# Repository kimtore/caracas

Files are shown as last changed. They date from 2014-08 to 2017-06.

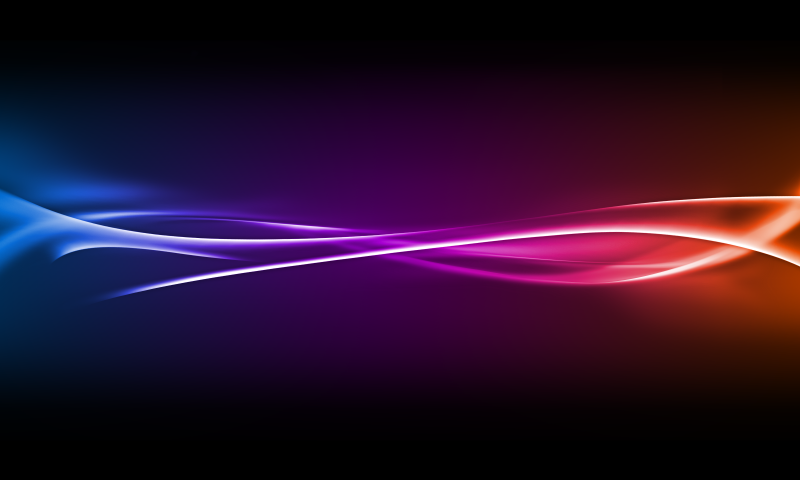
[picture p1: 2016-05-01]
etc/awesome/streamoflight.png

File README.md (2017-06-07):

# Caracas

Caracas is an open source DIY car stereo system for the Toyota Avensis 2007, running on Raspberry Pi with custom hardware modifications.

[See pictures](http://imgur.com/a/6FCoq) of Caracas in action!

## Features

* Front panel with volume button and a 800x480 resistive touch panel with backlight control.
* Control music and other functions using steering wheel control buttons.
* Ignition key detection: hardware controlled power-on, software-controlled power-off.
* Plays music using MPD, through a HIFImeDIY Sabre DAC ES9023 to a class D 400W RMS amplifier.
* ISO 10487 connection for power and speaker connections.
* Custom-designed Raspberry Pi HAT for interfacing with the car hardware.
* SSD disk stores huge amounts of music.
* 4G Internet connection using car antenna.
* GPS module using car antenna.
* Custom interface with music controls, using Qt.
* ~~World-wide road navigation using Marble and OpenStreetMap.~~

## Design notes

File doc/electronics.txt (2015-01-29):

http://www.electronics-tutorials.ws/transistor/tran_4.html

Voltage dividers:

    5V  -> 3.3V: r1=0.515*r2

    Try: r2 = 100k
         r1 = 47k

    12V -> 3.3V: r1=2.636*r2

    Try: r2 = 100k
         r1 = 290k

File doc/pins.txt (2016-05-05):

GPIO pin usage
--------------

8   TXD                 RS232   gps
10  RXD                 RS232   gps
16  Suicide out         OUTPUT  board, flip-flop reset
18  +12V ignition       INPUT   board, ignition on/off
20  GND                         header, rotary click
22  GPIO25              INPUT   header, rotary click
24  SPI CS              SPI     board
40  GPIO29              OUTPUT  display brightness 100Hz 3.3V PWM signal

7   GPCLK0              INPUT   gps, pulse per second
11  Amplifier power     OUTPUT  board, amplifier power switch
17  +3.3V to ADC
19  SPI MOSI            SPI
21  SPI MISO            SPI
23  SPI CLK             SPI
35  GPIO19              INPUT   header, rotary binary
37  GPIO26              INPUT   header, rotary binary
39  GND                         header, rotary binary

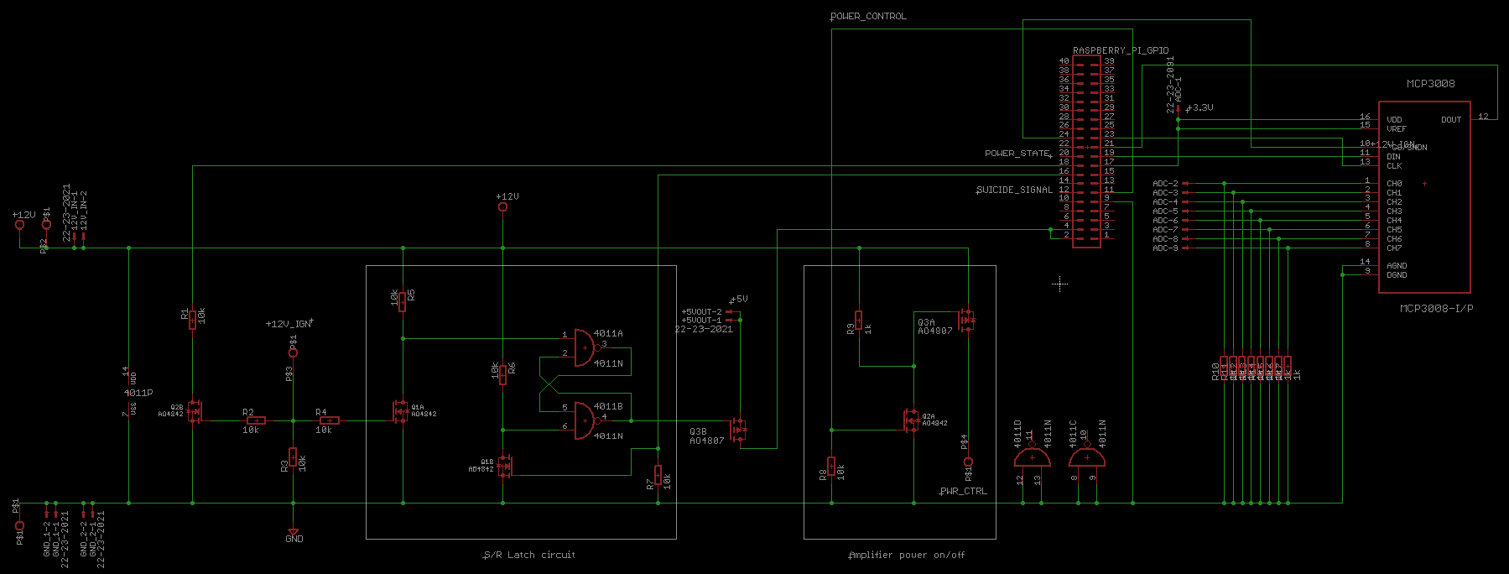
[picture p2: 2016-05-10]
doc/hat/schematic.png

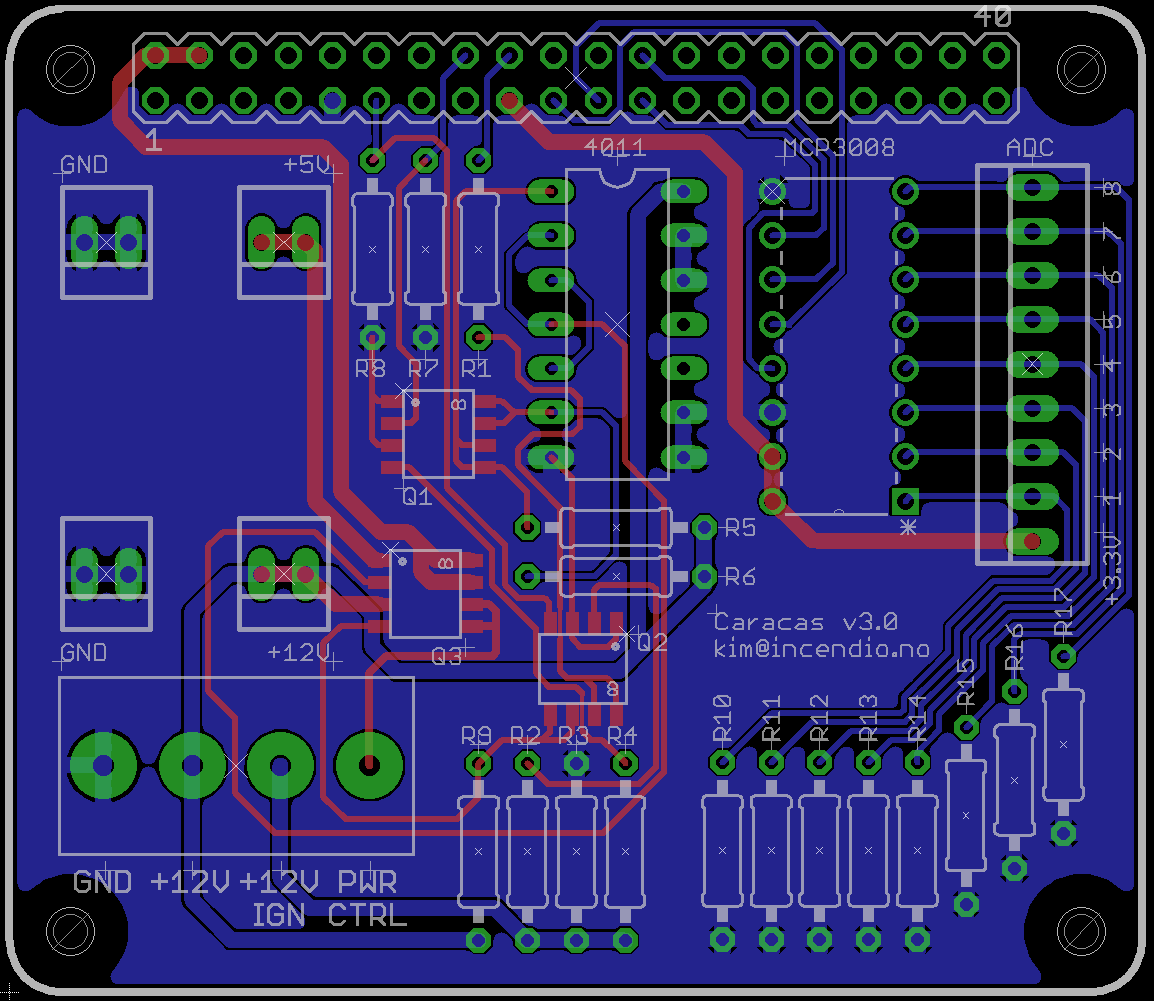
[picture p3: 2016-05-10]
doc/hat/layout.png

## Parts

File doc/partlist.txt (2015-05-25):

Partlist

Exported from untitled.sch at 5/25/15 12:14 PM

EAGLE Version 6.5.0 Copyright (c) 1988-2013 CadSoft

Assembly variant: 

Part              Value          Device       Package           Library   Sheet

+5VOUT            22-23-2021     22-23-2021   22-23-2021        con-molex 1
12V_IN            22-23-2021     22-23-2021   22-23-2021        con-molex 1
4011              4011N          4011N        DIL14             40xx      1
ADC               22-23-2091     22-23-2091   22-23-2091        con-molex 1
EXT               MKDS3          MKDS3        MKDS3             caracas   1
GND_1             22-23-2021     22-23-2021   22-23-2021        con-molex 1
GND_2             22-23-2021     22-23-2021   22-23-2021        con-molex 1
MCP1              MCP3008-I/P    MCP3008-I/P  DIP254P762X432-16 mpc3008   1
Q1                AO4842         AO4842       8-SOIC            caracas   1
Q2                AO4842         AO4842       8-SOIC            caracas   1
Q3                AO4807         AO4807       8-SOIC            caracas   1
R1                10k            R-EU_0207/10 0207/10           rcl       1
R2                10k            R-EU_0207/10 0207/10           rcl       1
R3                10k            R-EU_0207/10 0207/10           rcl       1
R4                10k            R-EU_0207/10 0207/10           rcl       1
R5                10k            R-EU_0207/10 0207/10           rcl       1
R6                10k            R-EU_0207/10 0207/10           rcl       1
R7                10k            R-EU_0207/10 0207/10           rcl       1
R8                10k            R-EU_0207/10 0207/10           rcl       1
R9                1k             R-EU_0207/10 0207/10           rcl       1
R10               1k             R-EU_0207/10 0207/10           rcl       1
R11               1k             R-EU_0207/10 0207/10           rcl       1
RASPBERRY_PI_GPIO                MA20-2       MA20-2            con-lstb  1

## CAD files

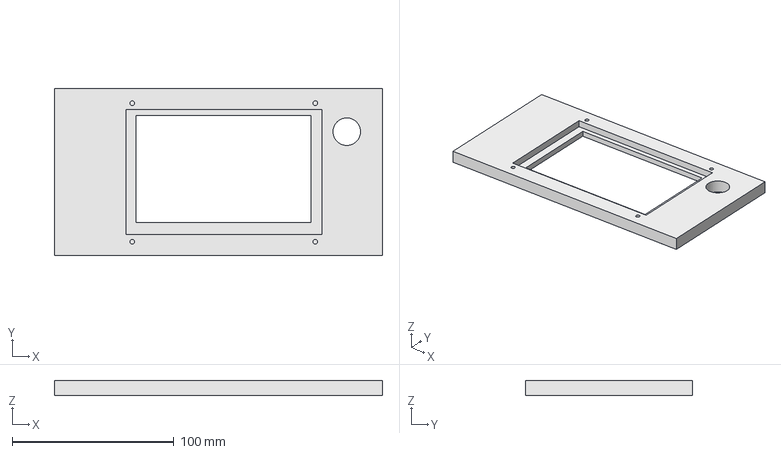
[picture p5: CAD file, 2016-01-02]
cad/panel.fcstd
202.5 x 102.9 x 9.00 mm

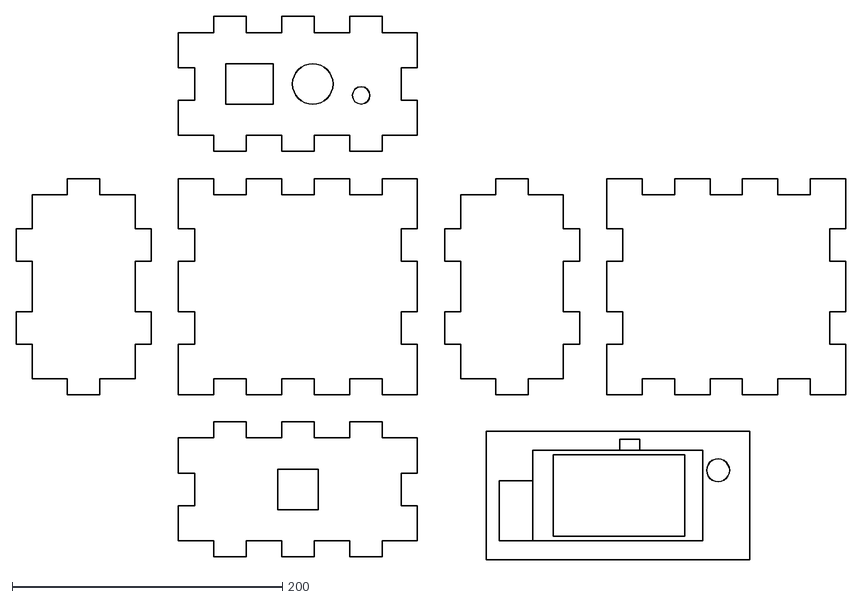
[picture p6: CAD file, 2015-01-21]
case/case.dxf
614.0 x 402.0

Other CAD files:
cad/panel-centered.fcstd
cad/panel-centered.dxf
cad/panel.dxf

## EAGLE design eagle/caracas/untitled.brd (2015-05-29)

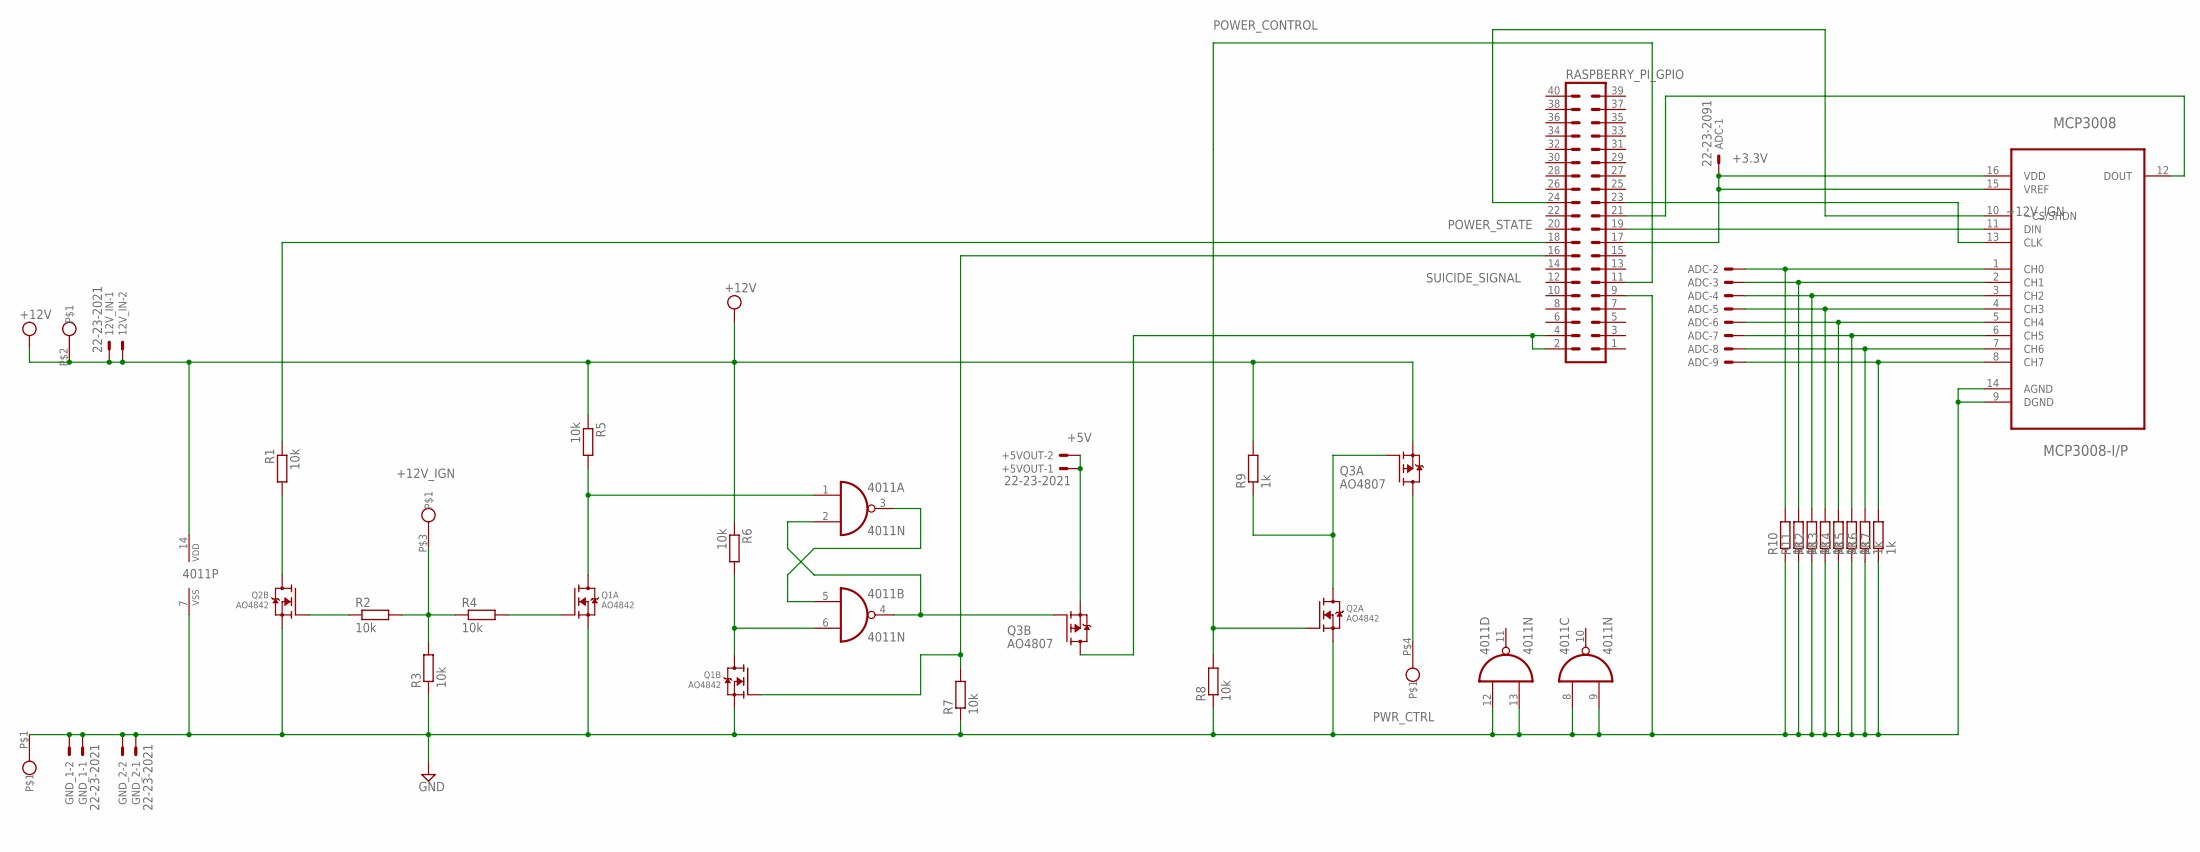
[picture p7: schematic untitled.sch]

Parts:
12V_IN: 22-23-2021
4011: 4011N; DIL14
+5VOUT: 22-23-2021
ADC: 22-23-2091
EXT: MKDS3
GND_1, GND_2: 22-23-2021
MCP3008: MCP3008-I/P; DIP254P762X432-16
Q1, Q2: AO4842; 8-SOIC
Q3: AO4807; 8-SOIC
R1, R2, R3, R4, R5, R6, R7, R8: 10k; 0207/10
R9, R10, R11, R12, R13, R14, R15, R16, R17: 1k; 0207/10
RASPBERRY_PI_GPIO: MA20-2

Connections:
+3.3V: ADC.1, MCP3008.15 (VREF), MCP3008.16 (VDD), RASPBERRY_PI_GPIO.17
+5V: +5VOUT.1, +5VOUT.2, Q3.P$1 (S)
+12V_IGN: EXT.P$3, R2.2, R3.2, R4.1
ANA_0: ADC.2, MCP3008.1 (CH0), R10.2
ANA_1: ADC.3, MCP3008.2 (CH1), R11.2
GND@BOTTOM: 4011.7 (VSS), 4011.8 (I0), 4011.9 (I1), 4011.12 (I0), 4011.13 (I1), EXT.P$1, GND_1.1, GND_1.2, GND_2.1, GND_2.2, MCP3008.9 (DGND), MCP3008.14 (AGND), Q1.P$1 (S), Q1.P$3 (S), Q2.P$1 (S), Q2.P$3 (S), R3.1, R7.1, R8.1, R10.1, R11.1, R12.1, R13.1, R14.1, R15.1, R16.1, R17.1, RASPBERRY_PI_GPIO.9
MOSFET_ON: 4011.2 (I1), 4011.4 (O), Q3.P$2 (G)
unnamed: 4011.3 (O), 4011.5 (I0)
unnamed: 4011.6 (I1), Q1.P$7 (D), Q1.P$8 (D), R6.2
unnamed: MCP3008.13 (CLK), RASPBERRY_PI_GPIO.23
unnamed: MCP3008.12 (DOUT), RASPBERRY_PI_GPIO.21
unnamed: MCP3008.11 (DIN), RASPBERRY_PI_GPIO.19
unnamed: ADC.4, MCP3008.3 (CH2), R12.2
unnamed: ADC.5, MCP3008.4 (CH3), R13.2
unnamed: ADC.6, MCP3008.5 (CH4), R14.2
unnamed: ADC.7, MCP3008.6 (CH5), R15.2
unnamed: 4011.1 (I0), Q1.P$5 (D), Q1.P$6 (D), R5.2
unnamed: Q1.P$4 (G), R4.2
unnamed: MCP3008.10 (~CS/SHDN), RASPBERRY_PI_GPIO.24
unnamed: ADC.8, MCP3008.7 (CH6), R16.2
unnamed: ADC.9, MCP3008.8 (CH7), R17.2
unnamed: Q3.P$7 (D), Q3.P$8 (D), RASPBERRY_PI_GPIO.2, RASPBERRY_PI_GPIO.4
unnamed: Q2.P$2 (G), R2.1
unnamed: Q2.P$7 (D), Q2.P$8 (D), R1.2
unnamed: Q2.P$5 (D), Q2.P$6 (D), Q3.P$4 (G), R9.1
POWER_CONTROL: Q2.P$4 (G), R8.2, RASPBERRY_PI_GPIO.11
POWER_STATE: R1.1, RASPBERRY_PI_GPIO.18
PWR_CTRL: EXT.P$4, Q3.P$5 (D), Q3.P$6 (D)
SUICIDE_SIGNAL: Q1.P$2 (G), R7.2, RASPBERRY_PI_GPIO.16
VCC: 12V_IN.1, 12V_IN.2, 4011.14 (VDD), EXT.P$2, Q3.P$3 (S), R5.1, R6.1, R9.2

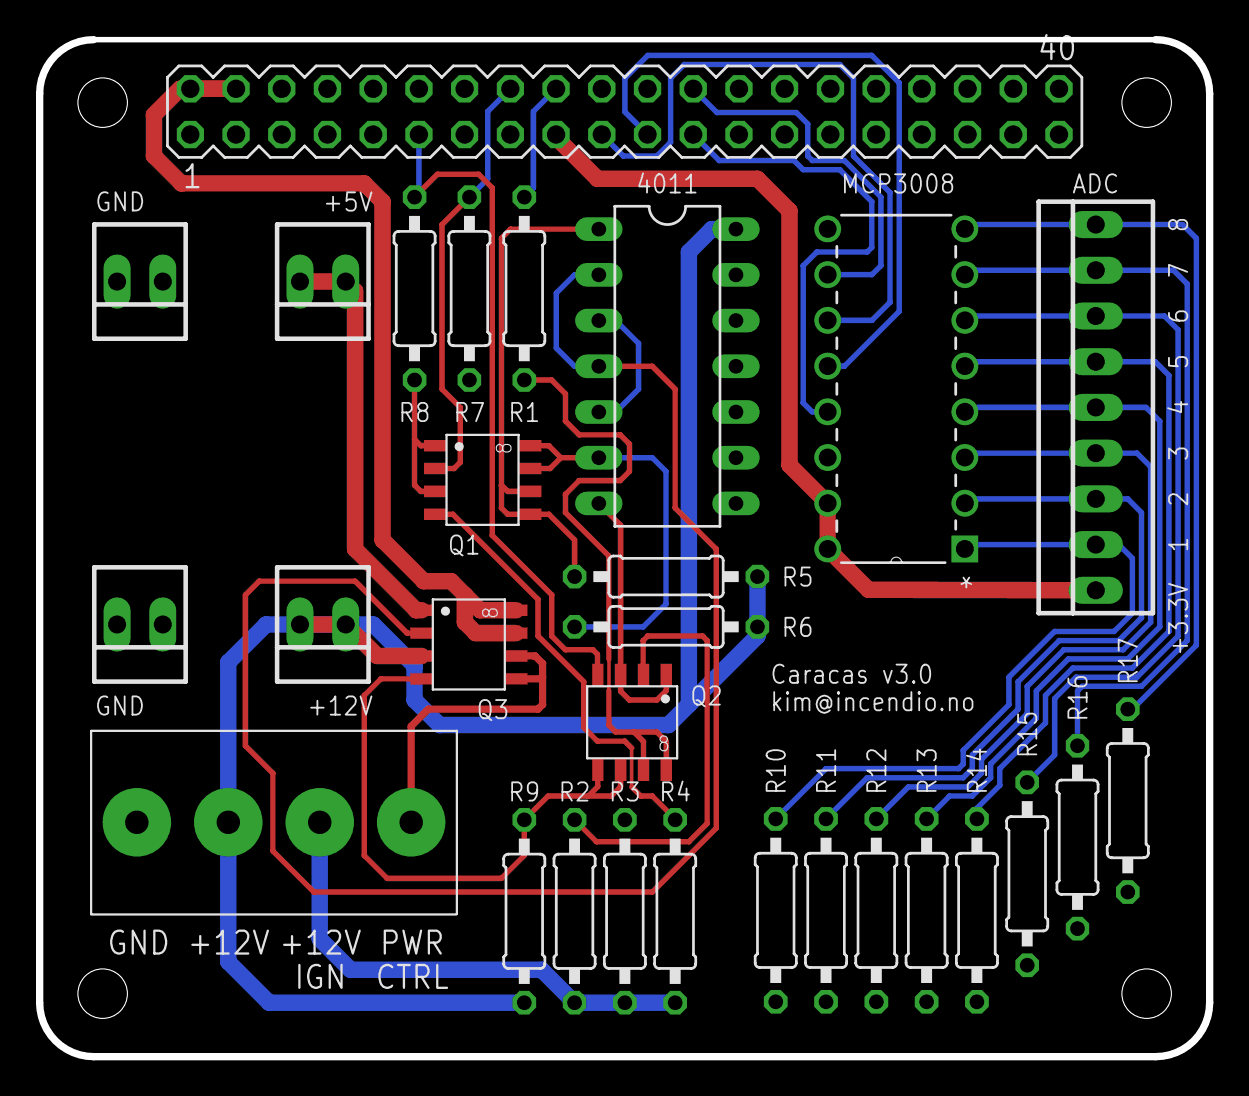
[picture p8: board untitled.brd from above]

Board: 2 copper layers, 65.0 x 56.5 mm, 29 parts (0 on the bottom side), 30 nets.

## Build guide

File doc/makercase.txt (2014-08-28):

http://www.makercase.com/
http://en.wikipedia.org/wiki/Connectors_for_car_audio - ISO 10487
http://en.wikipedia.org/wiki/ISO_7736

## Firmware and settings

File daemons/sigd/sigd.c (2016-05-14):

/**
 * Hardware event daemon for the CARACAS project.
 *
 * Monitors the Raspberry Pi's GPIO pins and uses ØMQ to emit events
 * when something happens.
 *
 * Requires the wiringPi library.
 */

#include <assert.h>
#include <string.h>
#include <stdlib.h>
#include <stdio.h>
#include <signal.h>
#include <wiringPi.h>
#include <mcp3004.h>
#include <zmq.h>
#include <syslog.h>

#define DEBUG_ADC 0
#define DEBUG 0

/*
 * Type definitions
 */
typedef signed char         int8_t;
typedef unsigned char       uint8_t;
typedef unsigned short      uint16_t;

/*
 * Rotary button input detect pins.
 * These pins are pulled LOW when the button is active.
 */
#define PIN_ROTARY_CLICK    6   /* BCM_GPIO pin 25, physical pin 22 */
#define PIN_ROTARY_RIGHT    25  /* BCM_GPIO pin 26, physical pin 37 */
#define PIN_ROTARY_LEFT     24  /* BCM_GPIO pin 19, physical pin 39 */

/**
 * Power state, input.
 * This pin is HIGH when the ignition key is switched on.
 */
#define PIN_POWER_STATE     5   /* BCM_GPIO pin 24, physical pin 18 */

/**
 * Max size of wiringPi pin numbering scheme
 */
#define PIN_MAX             101

/**
 * SPI parameters
 */
#define SPI_BASE            100
#define SPI_CHAN            0
#define SPI_PIN_MAX         2   /* How many pins to read, ranging from 1-8 */

/**
 * Microseconds interval between each read of the SPI controller
 */
#define SPI_INTERVAL        50000

/**
 * ADC steering wheel values
 */
#define ANALOG_MODE         1
#define ANALOG_UP           (1 << 1)
#define ANALOG_DOWN         (1 << 2)
#define ANALOG_VOL_UP       (1 << 3)
#define ANALOG_VOL_DOWN     (1 << 4)

/**
 * Exit codes
 */
#define EXIT_ZMQ            1
#define EXIT_WIRING         2
#define EXIT_SPI            3

/**
 * How long to run debouncing on the rotary click button
 */
#define DEBOUNCE_ITERATIONS 17

/**
 * Button events
 */
#define EVENT_NONE          0
#define EVENT_PRESS         1
#define EVENT_DEPRESS       2
#define EVENT_LEFT          3
#define EVENT_RIGHT         4

/**
 * ADC voltage lookup table
 */
uint8_t analog_table[SPI_PIN_MAX][1024];

/**
 * Program options
 */
struct opts_t {
    int running;
};

struct opts_t opts;

/**
 * ZeroMQ globals
 */
void *zmq_context;
void *zmq_publisher;

/**
 * Current state of pins
 */
uint8_t pin_state[PIN_MAX+1];

/**
 * Forward declarations
 */
void callback_rotary_binary();
void callback_rotary_click();
void callback_power_state();

/**
 * Save pin state in the pin_state struct.
 */
static void set_pin_state(uint8_t pin, uint8_t state)
{
    pin_state[pin] = state;
}

/**
 * Read pin state from the pin_state struct.
 */
static uint8_t get_pin_state(uint8_t pin)
{
    return pin_state[pin];
}

/**
 * Convert an event integer to a string.
 */
const char *event_name(uint8_t event)
{
    switch(event) {
        case EVENT_NONE:
            return "NONE";
        case EVENT_PRESS:
            return "PRESS";
        case EVENT_DEPRESS:
            return "DEPRESS";
        case EVENT_LEFT:
            return "LEFT";
        case EVENT_RIGHT:
            return "RIGHT";
        default:
            assert(0);
    }
}

/**
 * Convert active state to a string.
 */
const char *active_name(uint8_t active)
{
    return active ? "ON" : "OFF";
}

/**
 * Return true if a pin is considered active or pressed,
 * or false otherwise.
 */
static uint8_t pin_active(uint8_t pin)
{
    switch(pin) {
        case PIN_ROTARY_CLICK:
        case PIN_ROTARY_LEFT:
        case PIN_ROTARY_RIGHT:
        case PIN_POWER_STATE:
            return (get_pin_state(pin) == LOW);
        default:
            assert(0);
    }
}

/**
 * Pin initialization for rotary click button.
 */
static void init_pin_rotary_click()
{
    pinMode(PIN_ROTARY_CLICK, INPUT);
    pullUpDnControl(PIN_ROTARY_CLICK, PUD_UP);
    wiringPiISR(PIN_ROTARY_CLICK, INT_EDGE_BOTH, callback_rotary_click);
    set_pin_state(PIN_ROTARY_CLICK, HIGH);
}

/**
 * Pin initialization for rotary left switch.
 */
static void init_pin_rotary_left()
{
    pinMode(PIN_ROTARY_LEFT, INPUT);
    pullUpDnControl(PIN_ROTARY_LEFT, PUD_UP);
    wiringPiISR(PIN_ROTARY_LEFT, INT_EDGE_BOTH, callback_rotary_binary);
    set_pin_state(PIN_ROTARY_LEFT, HIGH);
}

/**
 * Pin initialization for rotary right switch.
 */
static void init_pin_rotary_right()
{
    pinMode(PIN_ROTARY_RIGHT, INPUT);
    pullUpDnControl(PIN_ROTARY_RIGHT, PUD_UP);
    wiringPiISR(PIN_ROTARY_RIGHT, INT_EDGE_BOTH, callback_rotary_binary);
    set_pin_state(PIN_ROTARY_RIGHT, HIGH);
}

/**
 * Pin initialization for power state input.
 */
static void init_pin_power_state()
{
    pinMode(PIN_POWER_STATE, INPUT);
    pullUpDnControl(PIN_POWER_STATE, PUD_UP);
    wiringPiISR(PIN_POWER_STATE, INT_EDGE_BOTH, callback_power_state);
    set_pin_state(PIN_POWER_STATE, HIGH);
}

/**
 * Initialize ADC communication with MPC3008.
 */
static void init_adc()
{
    /* 3004 and 3008 are the same, with 4/8 channels */
    if (mcp3004Setup(SPI_BASE, SPI_CHAN) != 0) {
        /* It seems that we are still able to read data even though we get a
         * non-zero exit code here, so we print the error without terminating. */
        perror("Error initializing SPI using MCP3008 chip");
        //exit(EXIT_SPI);
    }
}

/**
 * Initialize all input pins.
 */
static void init_pins()
{
    memset(&pin_state, 0, sizeof(pin_state));

    init_pin_rotary_click();
    init_pin_rotary_left();
    init_pin_rotary_right();
    init_pin_power_state();
}

/**
 * Convert a state into an event
 */
static uint8_t event_from_state(uint8_t state)
{
    return (state ? EVENT_DEPRESS : EVENT_PRESS);
}

/**
 * Check whether a pin has new events.
 */
static uint8_t get_pin_event(uint8_t pin)
{
    uint8_t state = digitalRead(pin);
    uint8_t old_state = get_pin_state(pin);

    set_pin_state(pin, state);

    return event_from_state(state);
}

/**
 * Check whether the rotary switch has events.
 */
static uint8_t get_rotary_event(uint8_t pin_left, uint8_t pin_right)
{
    static uint8_t state_left_old = 0;
    uint8_t state_left;
    uint8_t state_right;
    uint8_t event = EVENT_NONE;

    get_pin_event(pin_left);
    get_pin_event(pin_right);

    state_left = pin_active(pin_left);
    state_right = pin_active(pin_right);

    if (!state_left_old && state_left) {
        if (state_right) {
            event = EVENT_LEFT;
        } else {
            event = EVENT_RIGHT;
        }
    }
    state_left_old = state_left;

    return event;
}

/**
 * Send an event using ZeroMQ, and log the output.
 */
static int log_zmq_send(void *socket, const char *str)
{
    syslog(LOG_INFO, "Publishing ZeroMQ event: %s", str);
    return zmq_send(socket, str, strlen(str), 0);
}

/**
 * Send a normalized ZeroMQ event
 */
void simple_zmq_send(const char *source, const char *state)
{
    char msg[32];

    sprintf(msg, "%s %s", source, state);

    if (log_zmq_send(zmq_publisher, msg) == -1) {
        perror("Error when publishing ZeroMQ event");
    }
}

/**
 * One iteration of the debounce code.
 * Returns the debounced pin value 0/1, or -1 if there is no valid reading.
 */
int8_t debounce(uint16_t *state, uint8_t pin)
{
    *state = (*state << 1) | digitalRead(pin);
#if DEBUG
    syslog(LOG_DEBUG, "debounce %d %x", pin, *state);
#endif
    if (*state == 0x0000) {
        return 0;
    } else if (*state == 0xffff) {
        return 1;
    } else {
        return -1;
    }
}

/**
 * Make sure that 16 concurrent pin reads all read the same value
 */
int8_t read_debounced(uint8_t pin)
{
    int8_t value = -1;
    uint16_t state = 0x1010;
    struct timeval tend;
    struct timeval tstart;
    uint16_t iterations = DEBOUNCE_ITERATIONS;

    gettimeofday(&tstart, NULL);

    while (--iterations != 0) {
        value = debounce(&state, pin);
        if (value != -1) {
            return value;
        }
        usleep(1000);
    }

    return -1;
}

/**
 * Inner main loop for rotary binary switch.
 */
void callback_rotary_binary()
{
    char msg[32];
    uint8_t event;

    event = get_rotary_event(PIN_ROTARY_LEFT, PIN_ROTARY_RIGHT);

    if (event == EVENT_NONE) {
        return;
    }

    simple_zmq_send("ROTARY", event_name(event));
}

/**
 * Detect rotary click events
 */
void callback_rotary_click()
{
    uint8_t event;
    int8_t result;
    
    result = read_debounced(PIN_ROTARY_CLICK);
    if (result == -1) {
        syslog(LOG_DEBUG, "Encountered some noise on rotary click pin");
        return;
    }

    event = get_pin_event(PIN_ROTARY_CLICK);
    if (event == EVENT_NONE) {
        syslog(LOG_DEBUG, "Wrong event on rotary click pin, unexpected %s", event_name(event));
        return;
    }

    simple_zmq_send("ROTARY", event_name(event));
}

/**
 * Callback function for power state interrupt
 */
void callback_power_state()
{
    uint8_t event;
    uint8_t active;
    int8_t result;
    const char *name;
    
    result = read_debounced(PIN_POWER_STATE);
    if (result == -1) {
        syslog(LOG_DEBUG, "Encountered some noise on power pin");
        return;
    }

    event = get_pin_event(PIN_POWER_STATE);
    if (event == EVENT_NONE) {
        syslog(LOG_DEBUG, "Wrong event on power pin, unexpected %s", event_name(event));
        return;
    }

    active = pin_active(PIN_POWER_STATE);
    name = active_name(active);

    simple_zmq_send("POWER", name);
}

/**
 * Initialize options.
 */
static void clear_opts(struct opts_t *o)
{
    o->running = 1;
}

/**
 * Catch signals from operating system.
 */
void signal_handler(int s)
{
    syslog(LOG_NOTICE, "Caught signal %d", s);
    opts.running = 0;
}

/**
 * Initialize ADC lookup table
 *
 * Resistance between pins as follows:
 *
 * Function    Pin1    Pin2    Resistance      ADC value ref=3.33V divider=1k
 * --------------------------------------------------------------------------
 *             6       7       100.000 ohm     9    - 10
 *             6       8       100.000 ohm     9    - 10
 * Mode        6       8       1 ohm           1014 - 1023 (0 ohm)
 * Up          6       7       1 ohm           1014 - 1023 (0 ohm)
 * Down        6       7       330 ohm         764  - 769
 * Vol+        6       7       1.000 ohm       503  - 511
 * Vol-        6       7       3.100 ohm       243  - 250
 *
 */
void init_analog_table()
{
    uint16_t i;

    memset(&analog_table, 0, sizeof(analog_table));

    for (i = 1014; i <= 1023; i++) {
        analog_table[1][i] = ANALOG_MODE;
    }

    for (i = 1014; i <= 1023; i++) {
        analog_table[0][i] = ANALOG_UP;
    }

    for (i = 764; i <= 769; i++) {
        analog_table[0][i] = ANALOG_DOWN;
    }

    for (i = 503; i <= 511; i++) {
        analog_table[0][i] = ANALOG_VOL_UP;
    }

    for (i = 243; i <= 250; i++) {
        analog_table[0][i] = ANALOG_VOL_DOWN;
    }
}

/**
 * Process any changed events
 */
void handle_adc_events(uint8_t events, uint8_t last_events)
{
    uint8_t changed = events ^ last_events;
    uint8_t event;
    uint8_t state;

#if DEBUG_ADC
    syslog(LOG_DEBUG, "handle_adc_events: events=%d, last_events=%d, changed=%d", events, last_events, changed);
#endif

    if (changed & ANALOG_MODE) {
        event = event_from_state(!(events & ANALOG_MODE));
        simple_zmq_send("MODE", event_name(event));
    }
    if (changed & ANALOG_VOL_UP) {
        event = event_from_state(!(events & ANALOG_VOL_UP));
        simple_zmq_send("VOLUME UP", event_name(event));
    }
    if (changed & ANALOG_VOL_DOWN) {
        event = event_from_state(!(events & ANALOG_VOL_DOWN));
        simple_zmq_send("VOLUME DOWN", event_name(event));
    }
    if (changed & ANALOG_UP) {
        event = event_from_state(!(events & ANALOG_UP));
        simple_zmq_send("ARROW UP", event_name(event));
    }
    if (changed & ANALOG_DOWN) {
        event = event_from_state(!(events & ANALOG_DOWN));
        simple_zmq_send("ARROW DOWN", event_name(event));
    }
}

/**
 * Read from MCP3008.
 */
static uint8_t get_adc_event()
{
    static uint8_t last_events = 0;
    uint8_t events = 0;
    uint8_t pin;
    uint16_t voltage;

    for (pin = 0; pin < SPI_PIN_MAX; pin++) {
        voltage = analogRead(SPI_BASE + SPI_CHAN + pin);
#if DEBUG_ADC
        syslog(LOG_DEBUG, "Voltage value from ADC channel %d pin %d: voltage=%d event=%d", SPI_CHAN, pin, voltage, analog_table[pin][voltage]);
#endif
        events |= analog_table[pin][voltage];
    }

    if (events != last_events) {
        handle_adc_events(events, last_events);
    }

    last_events = events;
}

/**
 * Main program.
 */
int main(int argc, char **argv)
{
    zmq_context = zmq_init(1);
    zmq_publisher = zmq_socket(zmq_context, ZMQ_PUB);
    struct sigaction act;

    if ((zmq_connect(zmq_publisher, "tcp://localhost:9080")) != 0) {
        perror("Fatal error: could not connect to ZMQ socket tcp://localhost:9080");
        return EXIT_ZMQ;
    }

    if (wiringPiSetup()) {
        perror("Fatal error: could not initialize wiringPi");
        return EXIT_WIRING;
    }

    openlog("sigd", LOG_PID, LOG_DAEMON);

    init_pins();
    init_adc();
    init_analog_table();

    act.sa_handler = signal_handler;
    act.sa_flags = 0;
    sigemptyset(&act.sa_mask);
    sigaction(SIGTERM, &act, NULL);
    sigaction(SIGINT, &act, NULL);

    clear_opts(&opts);

    syslog(LOG_NOTICE, "Caracas daemon started.");

    while (opts.running) {
        get_adc_event();
        usleep(SPI_INTERVAL);
    }

    syslog(LOG_NOTICE, "Received shutdown signal, exiting.");

    zmq_close(zmq_publisher);
    zmq_term(zmq_context);

    return 0;
}

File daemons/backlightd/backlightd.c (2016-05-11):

/**
 * Hardware event daemon for the CARACAS project.
 *
 * Monitors the Raspberry Pi's GPIO pins and uses ØMQ to emit events
 * when something happens.
 *
 * Requires the wiringPi library.
 */

#include <assert.h>
#include <string.h>
#include <stdlib.h>
#include <stdio.h>
#include <wiringPi.h>
#include <mcp3004.h>
#include <zmq.h>
#include <syslog.h>

/**
 * Type definitions
 */
typedef signed char         int8_t;
typedef unsigned char       uint8_t;
typedef unsigned short      uint16_t;

/**
 * Pulse width modulation output pin for Adafruit display backlight regulation.
 */
#define PIN_BACKLIGHT_PWM   29  /* BCM_GPIO pin 21, physical pin 40 */

/**
 * Set the range of the PWM pin to 0-100. That means steps in increments of
 * 10Hz are possible, from 0-1kHz. The screen is initialized with full intensity.
 */
#define PWM_INITIAL_VALUE   100
#define PWM_RANGE           100

/**
 * The string that starts a backlight adjustment command.
 */
#define BACKLIGHT_CMD       "BACKLIGHT "

/**
 * Exit codes
 */
#define EXIT_ZMQ            1
#define EXIT_WIRING         2
#define EXIT_SPI            3

/**
 * Program options
 */
struct opts_t {
    int running;
};

struct opts_t opts;

/**
 * ZeroMQ globals
 */
void *zmq_context;
void *zmq_publisher;
void *zmq_sock;

/**
 * Initialize PWM output pin.
 */
static void init_pin()
{
    softPwmCreate(PIN_BACKLIGHT_PWM, PWM_INITIAL_VALUE, PWM_RANGE);
}

/**
 * Convert a intensity percentage to a PWM value.
 */
static uint16_t percentage_to_value(uint16_t percentage)
{
    return (percentage / 100.0) * PWM_RANGE;
}

/**
 * Returns a percentage value from a ZeroMQ message, or -1 if the message is invalid.
 */
static int16_t percentage_from_message(const char * msg)
{
    msg += strlen(BACKLIGHT_CMD);
    return atoi(msg);
}

/**
 * Send an event using ZeroMQ, and log the output.
 */
static int log_zmq_send(void *socket, const char *str)
{
    syslog(LOG_INFO, "Publishing ZeroMQ event: %s", str);
    return zmq_send(socket, str, strlen(str), 0);
}

/**
 * Send a normalized ZeroMQ event
 */
void simple_zmq_send(const char *source, const char *state)
{
    char msg[32];

    sprintf(msg, "%s %s", source, state);

    if (log_zmq_send(zmq_publisher, msg) == -1) {
        perror("Error when publishing ZeroMQ event");
    }
}

/**
 * Initialize options.
 */
static void clear_opts(struct opts_t *o)
{
    o->running = 1;
}

/**
 * Main program.
 */
int main(int argc, char **argv)
{
    int err;
    char buf[128];
    int16_t percentage;
    uint16_t value;

    openlog("backlightd", LOG_PID, LOG_DAEMON);

    syslog(LOG_INFO, "Starting backlight daemon.");

    /* Create ZeroMQ context */
    zmq_context = zmq_ctx_new();
    if (!zmq_context) {
        syslog(LOG_EMERG, "Failed to create ZeroMQ context: %s", zmq_strerror(errno));
        return EXIT_FAILURE;
    }

    /* Create ZeroMQ socket */
    zmq_sock = zmq_socket(zmq_context, ZMQ_SUB);
    if (!zmq_sock) {
        syslog(LOG_EMERG, "Failed to create ZeroMQ socket: %s", zmq_strerror(errno));
        return EXIT_FAILURE;
    }

    /* Subscribe to everything */
    if (zmq_setsockopt(zmq_sock, ZMQ_SUBSCRIBE, BACKLIGHT_CMD, strlen(BACKLIGHT_CMD)) == -1) {
        syslog(LOG_EMERG, "Failed to set ZeroMQ socket options: %s", zmq_strerror(errno));
        return EXIT_FAILURE;
    }

    /* Connect to ZeroMQ publisher */
    if (zmq_connect(zmq_sock, "tcp://localhost:9090") == -1) {
        syslog(LOG_EMERG, "Failed to connect to ZeroMQ publisher: %s", zmq_strerror(errno));
        return EXIT_FAILURE;
    }

    syslog(LOG_INFO, "Connected to ZeroMQ publisher.");

    if (wiringPiSetup()) {
        perror("Fatal error: could not initialize wiringPi");
        return EXIT_WIRING;
    }

    init_pin();

    clear_opts(&opts);

    syslog(LOG_NOTICE, "Backlight daemon started.");

    while (opts.running) {
        err = zmq_recv(zmq_sock, buf, 128, 0);
        if (err < 0) {
            syslog(LOG_ERR, "Failed to receive data from ZeroMQ publisher: %s", zmq_strerror(errno));
            break;
        }
        buf[err] = '\0';
        // syslog(LOG_DEBUG, "Received ZeroMQ message: %s", buf);
        percentage = percentage_from_message(buf);
        if (percentage < 0 || percentage > 100) {
            continue;
        }
        value = percentage_to_value(percentage);
        // syslog(LOG_INFO, "Setting backlight to %d%% (value %d)", percentage, value);
        softPwmWrite(PIN_BACKLIGHT_PWM, value);
    }

    syslog(LOG_NOTICE, "Received shutdown signal, exiting.");

    zmq_close(zmq_sock);
    zmq_term(zmq_context);

    return 0;
}

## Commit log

2014-08-21 Add CAD files and Fritzing file.
    [assembled.fcstd, casing.fcstd, power_board.fzz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]
2014-08-22 Update some CAD and fritzing drawings.
    [casing.fcstd, power_board.fzz]
2014-08-28 Add WIP.
    [power.kicad_pcb, power.sch]
2014-08-29 Add Eagle schematics.
    [untitled.brd, untitled.sch]
2014-09-16 Update Eagle project.
    [untitled.brd, untitled.sch]
2014-09-16 Update Eagle schematics.
    [untitled.brd, untitled.sch]
2014-09-23 Add the CD2109 SATA connector datasheet.
2014-09-23 Add the CD2109 SATA connector to EAGLE library.
2014-09-23 EAGLE: draw SATA connector into schematics.
    [untitled.brd, untitled.sch]
2014-09-23 Finished design?
    [untitled.brd, untitled.sch]
2014-10-21 Save the board again.
    [untitled.brd, untitled.sch]
2014-12-07 Add 177x180x100mm case plans with makercase.com
2014-12-07 Add Toyota wiring harness documentation.
2014-12-07 Update the case plans with holes and front panel.
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2014-12-16 WIP on electronics schematics.
    [untitled.brd, untitled.sch]
2014-12-16 Update case plans with 12mm thick material.
2014-12-16 WIP on electronics schema.
    [untitled.sch]
2014-12-17 More WIP on the electronics schematics, closing in...
    [untitled.brd, untitled.sch]
2014-12-18 Schematic and board finished (at least R1)
    [untitled.brd, untitled.sch]
2014-12-18 Fixed a design bug
    [untitled.brd]
2014-12-27 Update case and panel dimensions, split into two documents, add demo PDF
2014-12-28 SPI clock in on pin 23, not pin 5
    [untitled.brd, untitled.sch]
2014-12-29 Fixed errors in the electrical diagram.
    [untitled.brd, untitled.sch]
2015-01-08 New case dimensions, and add exported DXF files.
    [case.dxf, panel.dxf]
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2015-01-10 Case design modified again, this time using an Inkscape plugin.
    [case.dxf]
2015-01-10 Schematics: replace CD4027N J/K flip-flop with 4011N nand gates.
    [untitled.brd, untitled.sch]
2015-01-14 Remove obsolete component from electronics schematics. Clean up board paths.
    [untitled.brd, untitled.sch]
2015-01-21 Use correct size for DC/DC converter, and compress size of board.
    [untitled.brd]
2015-01-21 Move panel design into the rest of the case design.
    [case.dxf, panel.dxf]
2015-01-29 Update schematics again.
    [untitled.brd, untitled.sch]
2015-01-29 Assign values to resistors.
    [untitled.brd, untitled.sch]
2015-02-05 WIP schematics
    [untitled.brd, untitled.sch]
2015-02-05 Document ADC value on voltage divider for steering controls.
2015-02-05 WIP electronics.
    [untitled.brd, untitled.sch]
2015-02-08 Possibly last version of schematics.
    [untitled.brd, untitled.sch]
2015-02-08 Schematics adjusted once again.
    [untitled.brd, untitled.sch]
2015-02-12 Switch to wiringPi library, rewrite rotary pin detection code.
2015-02-12 Implement rotary switch detection code.
2015-02-12 Add documentation and stub out MPC3008 SPI access.
2015-03-26 Add daemon 'suicided', shutting down system when ignition power disappears
2015-03-26 Use interrupts for main loop instead of timing delay
2015-03-26 Add power state monitoring to sigdaemon
2015-03-26 Clean up sigdaemon and add debouncing of switches.
2015-04-03 Refactor hardware board into a Raspberry PI B+ compatible HAT board
    [untitled.brd, untitled.sch]
2015-04-04 Add Raspberry PI HAT board mechanical documentation
2015-04-04 Commit some android build.props
2015-04-05 Add Raspberry PI GPIO image schematic
2015-04-05 Small board layout changes
    [untitled.brd]
2015-04-06 Document stereo cage physical dimensions required for hole drilling
2015-04-11 Begin describing pin mapping
2015-04-16 Update schematics again
    [untitled.brd, untitled.sch]
2015-04-16 Power board: route power buses on top layer
    [untitled.brd]
2015-04-16 Final board v2.0
    [untitled.brd, untitled.sch]
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2015-04-16 Add 40-pin header datasheet
2015-05-10 Add ADC test program 'wicked'
2015-05-10 Power state pin changed to 18 in board layout v2
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2015-05-14 Power board v2 does not work, start working on v3
    [untitled.brd, untitled.sch]
2015-05-25 More schematics WIP
    [untitled.brd, untitled.sch]
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2015-05-27 Complete rework of the PCB
    [untitled.brd, untitled.sch]
2015-05-29 Remove a polygon
    [untitled.brd]
2015-05-29 Update board
    [untitled.brd]
2015-05-29 Add Gerber files for v3.0 board
    [untitled.GBL, untitled.GBO, untitled.GBP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]
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2015-06-17 Hardware button fixes
2015-06-18 Adjust steering wheel pin values by actual measurements
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2015-06-28 Add webservice code, listens for battery events from Android
2015-06-28 Add support for Android battery state in car daemon
2015-06-28 Fixes on the last commits, upgrading to ZMQ 4.x
    [sigd.c]
2015-06-28 Fix a couple of bugs, add screen support in webservice
    [sigd.c]
2015-06-28 Switch off display and music when ignition power is lost
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2015-07-14 Board pinout changing when adding the Adafruit Ultimate GPS HAT
2015-07-20 Swap rotary left and right pins
    [sigd.c]
2015-07-20 Always switch on music when system boots, and switch screen and music off as fast as possible.
2015-07-21 Always keep the system powered on if /tmp/keepalive exists
2015-07-29 Workaround ZeroMQ socket startup and boot sequencing
2016-01-02 Add panel design file
    [panel.fcstd]
2016-01-02 Make sure distance to left edge of panel is 44 mm
    [panel.fcstd]
2016-01-02 Attempt an export of the panel CAD drawing to DXF format
    [panel.dxf]
2016-01-02 Add centered panel versions
    [panel-centered.dxf, panel-centered.fcstd]
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2016-05-02 Switch out SystemV init scripts with systemd services and targets
2016-05-02 Add missing sigd and gitignore files
    [sigd.c]
2016-05-03 Fix a couple of systemd related Ansible bugs
2016-05-06 Fix backlightd ZeroMQ interrupts
    [backlightd.c]
2016-05-08 Commit screenshots of version 3 of the Raspberry Pi HAT
2016-05-08 Clean up documentation directory
    [power_board.fzz]
2016-05-12 Power-off after 15 minutes instead of 1 hour
2016-05-13 System shutdown with systemctl is shutdown, not poweroff
2016-05-14 sigdaemon: don't ignore double states, interferes with ignition key event
    [sigd.c]
